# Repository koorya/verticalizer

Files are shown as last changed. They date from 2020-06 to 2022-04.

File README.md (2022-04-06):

# Вертикализатор

Репозиторий включает в себя несколько направлений разработки.
 - Hardware - проект схемы и разводки модернизированной печатной платы панели прибора
 - Production - материалы, передаваемые в производство платы
 - Firmware - состоит из двух частей: plc_cp1l - проект прошики ПЛК, python - submodule с примером общений с прибором из ПК
 - CAD - чертежи корпусов устройства
 - Docs - справочная информация по используемым компонентам

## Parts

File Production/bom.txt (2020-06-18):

Partlist exported from C:/Users/Puakt/Documents/EAGLE/projects/verticalizer/Hardware/panel.sch at 18.06.2020 19:30

Qty Value          Device         Package                           Parts                                                                                                                                              Description                                                                                                   MF    MPN OC_FARNELL OC_NEWARK POPULARITY SPICEPREFIX
1                  1,6/0,8        1,6/0,8                           PAD1                                                                                                                                               THROUGH-HOLE PAD                                                                                                                             15                    
1   0.1uF          CPOL-EUCT3216  CT3216                            C3                                                                                                                                                 POLARIZED CAPACITOR, European symbol                                                                                                         1          C          
1   0.33uF         CPOL-EUCT3216  CT3216                            C2                                                                                                                                                 POLARIZED CAPACITOR, European symbol                                                                                                         1          C          
1   10uF 16v       CPOL-EUCT3216  CT3216                            C1                                                                                                                                                 POLARIZED CAPACITOR, European symbol                                                                                                         1          C          
14  150            R-EU_R2512     R2512                             R48, R49, R50, R51, R52, R53, R54, R55, R56, R57, R58, R59, R60, R61                                                                               RESISTOR, European symbol                                                                                                                    0          R          
1   15k            R-EU_R0805     R0805                             R3                                                                                                                                                 RESISTOR, European symbol                                                                                                                    86         R          
7   2.2k           R-EU_R0805     R0805                             R14, R17, R20, R23, R26, R29, R32                                                                                                                  RESISTOR, European symbol                                                                                                                    86         R          
31  4.7k           R-EU_R0805     R0805                             R1, R4, R5, R6, R7, R8, R9, R10, R11, R12, R13, R15, R16, R18, R19, R21, R22, R24, R25, R27, R28, R30, R31, R33, R34, R36, R38, R40, R42, R44, R46 RESISTOR, European symbol                                                                                                                    86         R          
1   51             R-EU_R0805     R0805                             R2                                                                                                                                                 RESISTOR, European symbol                                                                                                                    86         R          
1   52746-20       52746-20       52746-20                          X2                                                                                                                                                 FPC Connector ZIF for SMT 0.5mm                                                                               MOLEX     9786350    unknown   0                     
5   7mm            TL11057MM      TL1105F                           S1, S2, S3, S4, S5                                                                                                                                                                                                                                                                                                    
7   800            R-EU_R0805     R0805                             R35, R37, R39, R41, R43, R45, R47                                                                                                                  RESISTOR, European symbol                                                                                                                    86         R          
1   B16B-PHDSS     B16B-PHDSS     B16B-PHDSS                        X1                                                                                                                                                 JST PHD series header 2.00mm pitch disconnectable crimp style connectors, vertical (side entry type), 16 pins                                                      
7   BC807-16LT1SMD BC807-16LT1SMD SOT23                             Q6, Q7, Q8, Q9, Q10, Q11, Q12                                                                                                                      PNP Transistror                                                                                                                              0                     
12  BC817-40LT1SMD BC817-40LT1SMD SOT23-BEC                         Q1, Q2, Q3, Q4, Q5, Q13, Q14, Q15, Q16, Q17, Q18, Q19                                                                                              NPN Transistor                                                                                                                               10                    
1   MC7805CDT      MC7805CDT      DPAK-3                            U1                                                                                                                                                 78xx SMD (D2PAK, DPAK)                                                                                                                                             
1   TSOP4838FLAT   TSOP4838FLAT   HDRVR14W64P250_1X14_2266X508X754B U$1                                                                                                                                                IR Receiver and Demodulator                                                                                                                                        
6   green          LEDGREEN_3MM   LED_GREEN_3MM                     LED2, LED3, LED4, LED5, LED6, LED7                                                                                                                 LED                                                                                                                                                                
1   red            LEDRED_3MM     LED_RED_3MM                       LED1                                                                                                                                               LED

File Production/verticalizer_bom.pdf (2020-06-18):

Комплект электронных компонентов для модификации вертикализатора.

кол-во | номинал | Device | Package | ссылка на магазин | изображение
1 | 0.1uF | CPOL-EUCT3216 | CT3216 | https://www.elitan.ru/price/item 444798 (https://www.elitan.ru/price/item444798)
1 | 0.33uF | CPOL-EUCT3216 | CT3216 | https://www.elitan.ru/price/item 531045 (https://www.elitan.ru/price/item531045)
1 | 10uF 16v | CPOL-EUCT3216 | CT3216 | https://www.elitan.ru/price/item 1692774 (https://www.elitan.ru/price/item1692774)
14 | 150ohm | R-EU_R2512 | R2512 | https://www.elitan.ru/price/item 13328558 (https://www.elitan.ru/price/item13328558)
1 | 15k | R-EU_R0805 | R0805
7 | 2.2k | R-EU_R0805 | R0805
31 | 4.7k | R-EU_R0805 | R0805

1 | 51ohm | R-EU_R0805 | R0805
7 | 800ohm | R-EU_R0805 | R0805
2 | 52746-20 | connector molex pn 527462033 | 52746-20 | https://www.elitan.ru/price/item 11015051 (https://www.elitan.ru/price/item11015051)
5 | 7mm | TL11057MM | TL1105F | https://www.elitan.ru/price/item 2132496 (https://www.elitan.ru/price/item2132496)
1 | B16B-PH DSS | B16B-PHDSS | B16B-PHDSS | https://www.elitan.ru/price/item 500178 (https://www.elitan.ru/price/item500178)
7 | BC807-16 LT1SMD | BC807-16LT1SMD | SOT23 | https://www.elitan.ru/price/item 77097 (https://www.elitan.ru/price/item77097)
12 | BC817-40 LT1SMD | BC817-40LT1SMD | SOT23-BEC | https://www.elitan.ru/price/item 1385191 (https://www.elitan.ru/price/item1385191)

1 | MC7805C DT | MC7805CDT | DPAK-3 | https://www.elitan.ru/price/item 99337 (https://www.elitan.ru/price/item99337)
1 | TSOP483 8FLAT | TSOP4838FLAT | HDRVR14W64P250_1X14_ 2266X508X754B | https://www.elitan.ru/price/item 127075 (https://www.elitan.ru/price/item127075)
6 | green | LEDGREEN_3MM | LED_GREEN_3MM | https://www.elitan.ru/price/item 16824792 (https://www.elitan.ru/price/item16824792)
1 | red | LEDRED_3MM | LED_RED_3MM | https://www.elitan.ru/price/item 16824793 (https://www.elitan.ru/price/item16824793)
1 | 2РМТ24КПН19Ш1В 1В | вилка на кабель | https://www.elitan.ru/price/item 260370335 (https://www.elitan.ru/price/item260370335)
1 | 2РМТ24БПЭ19Г1В 1В | розетка на блок | https://www.elitan.ru/price/item 211260919 (https://www.elitan.ru/price/item211260919)

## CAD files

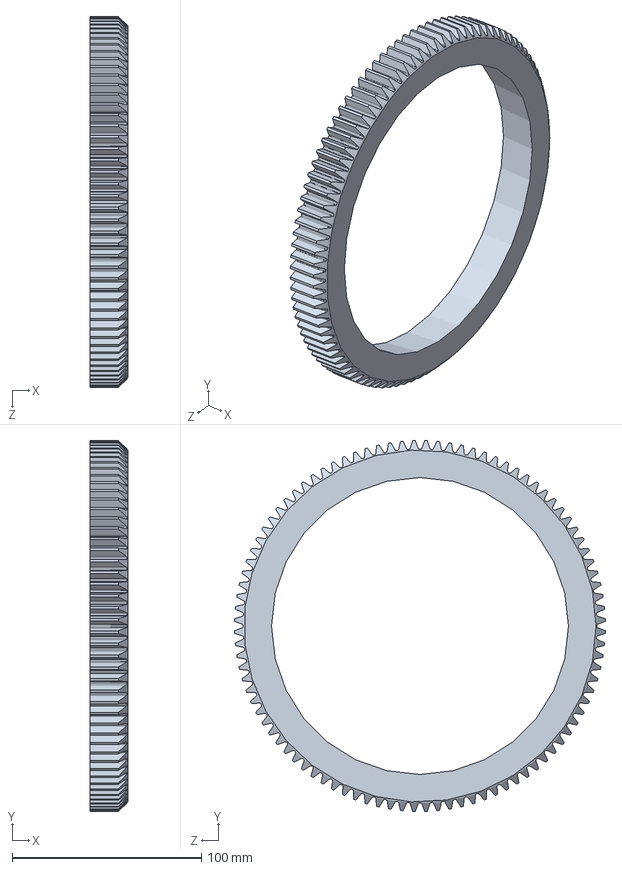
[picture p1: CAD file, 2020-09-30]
CAD/gears/DIN - Spur gear 2M 96T 20PA 12FW ---S96A75H50L155N новожилов.SLDPRT
20.0 x 195.9 x 195.9 mm

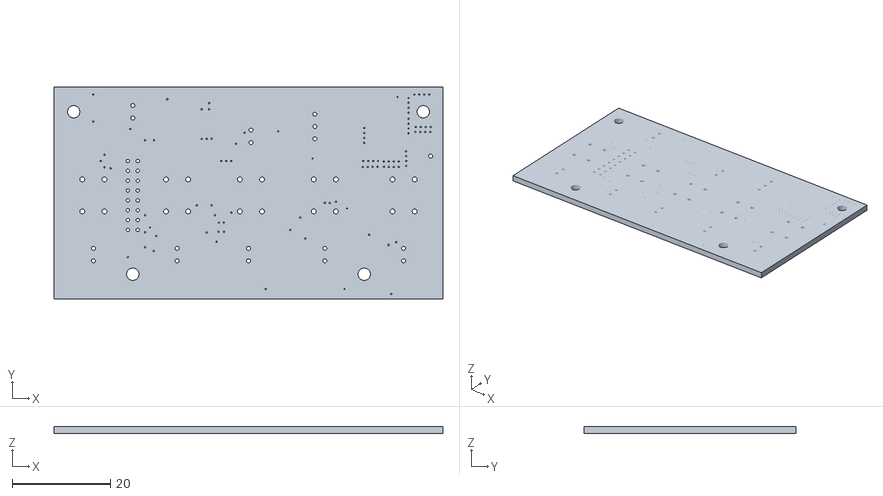
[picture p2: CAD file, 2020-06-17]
Production/Board.stl
79.0 x 43.0 x 1.50

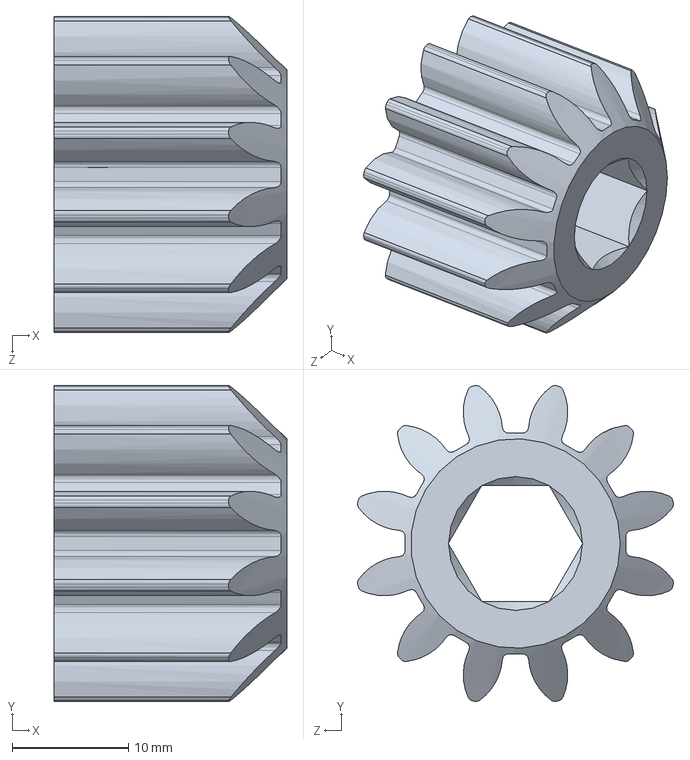
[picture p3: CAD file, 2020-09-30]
CAD/gears/DIN - Spur gear 2M 12T 20PA 16FW ---S12A75H50L6N новожилов.SLDPRT
20.0 x 27.1 x 27.1 mm

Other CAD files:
CAD/gears/DIN - Spur gear 2M 12T 20PA 16FW ---S12A75H50L6N новожилов.STL
CAD/gears/DIN - Spur gear 2M 96T 20PA 12FW ---S96A75H50L155N новожилов.STL
CAD/РФГМ-80 0210 Корпус шлейфа.x_t

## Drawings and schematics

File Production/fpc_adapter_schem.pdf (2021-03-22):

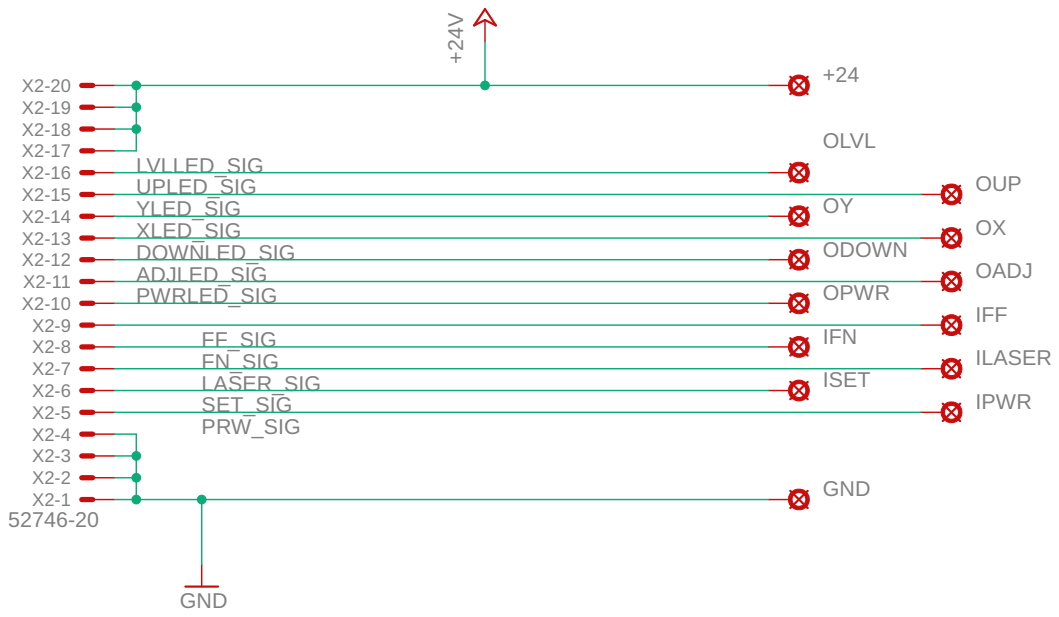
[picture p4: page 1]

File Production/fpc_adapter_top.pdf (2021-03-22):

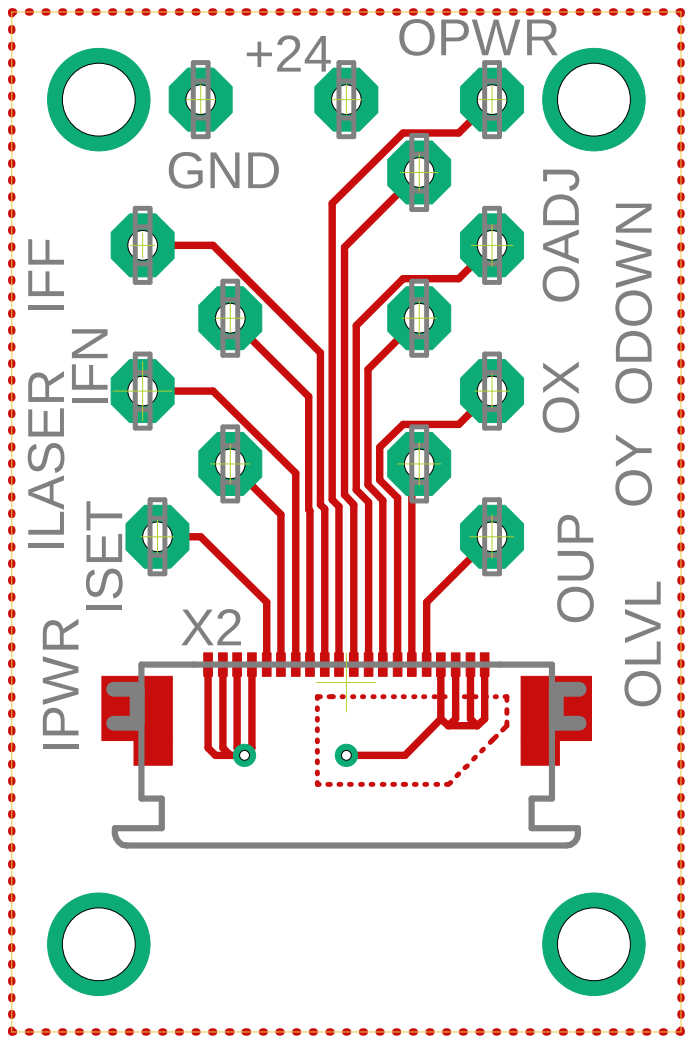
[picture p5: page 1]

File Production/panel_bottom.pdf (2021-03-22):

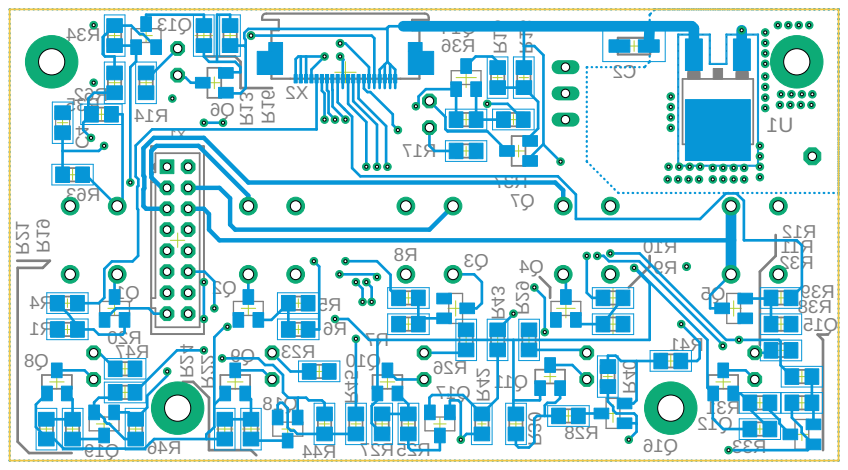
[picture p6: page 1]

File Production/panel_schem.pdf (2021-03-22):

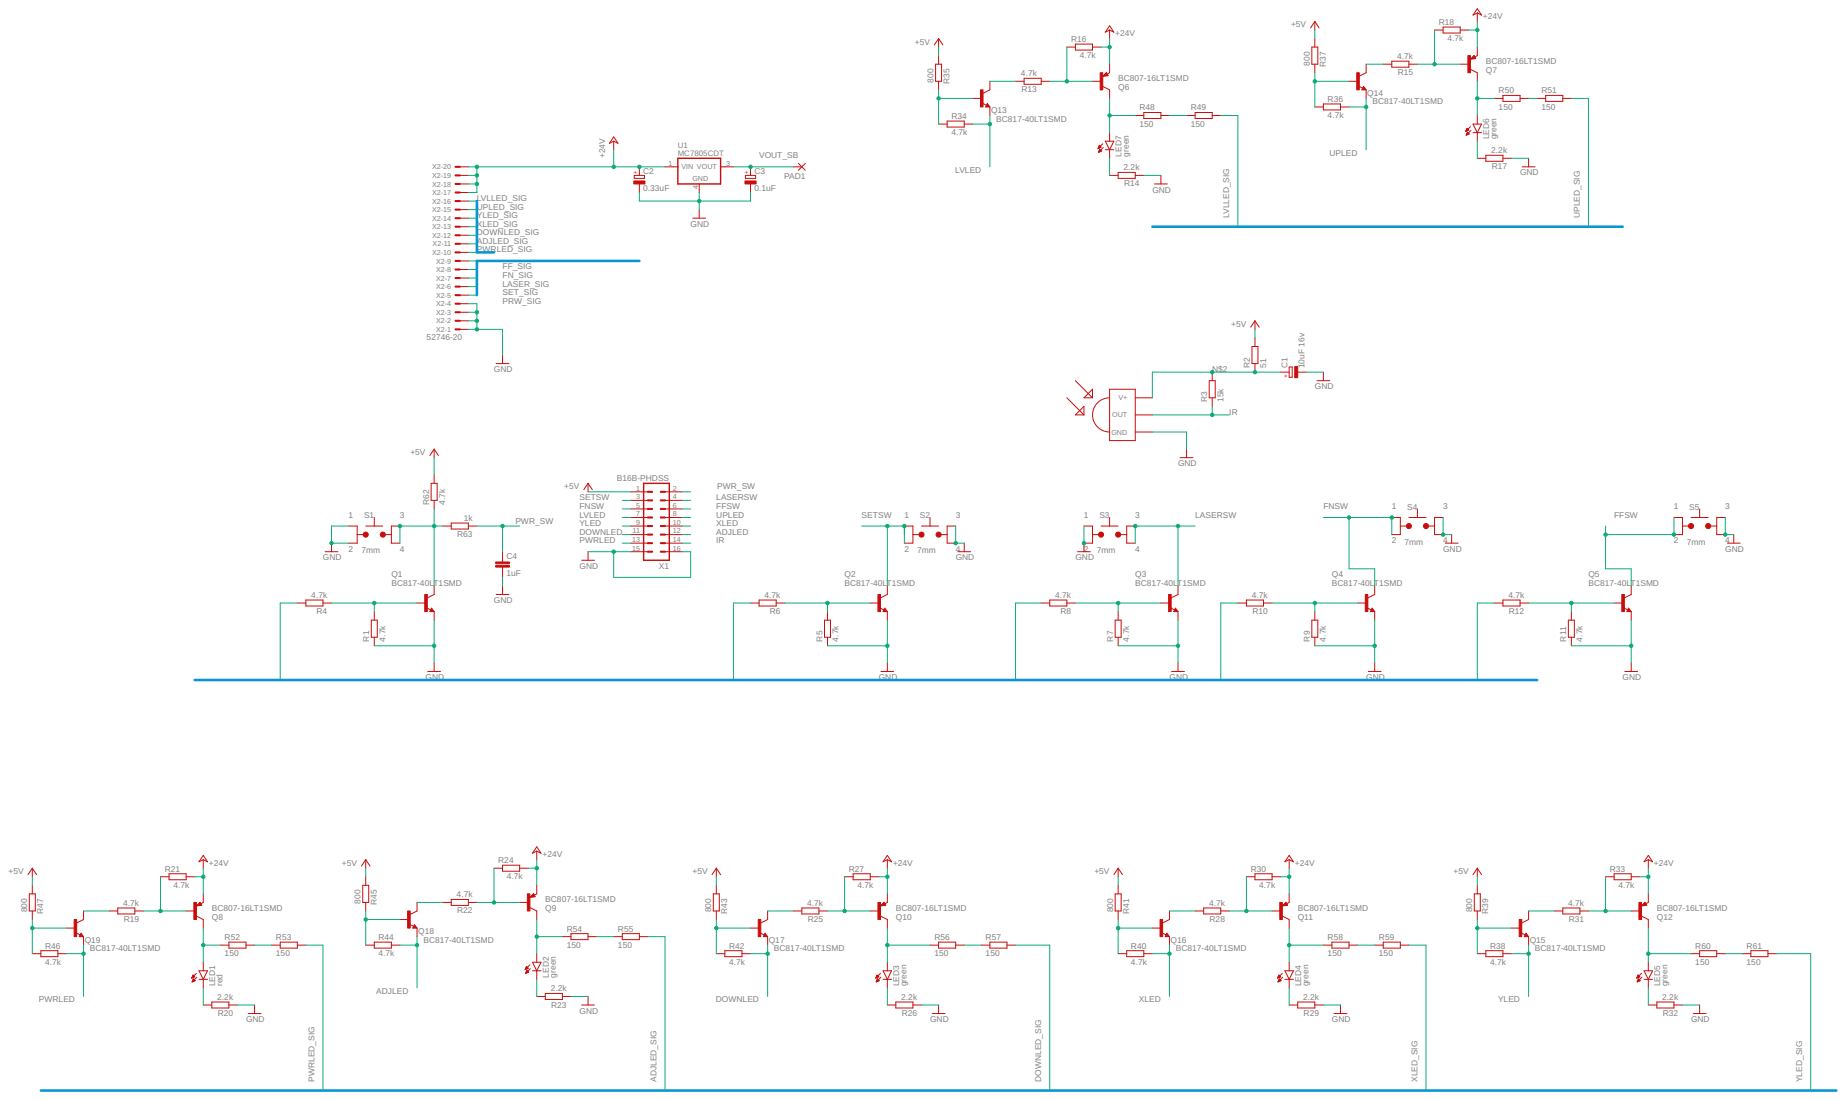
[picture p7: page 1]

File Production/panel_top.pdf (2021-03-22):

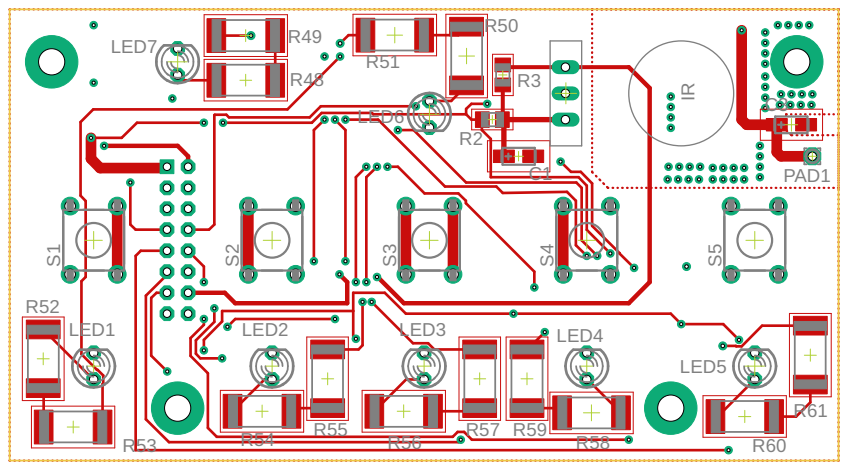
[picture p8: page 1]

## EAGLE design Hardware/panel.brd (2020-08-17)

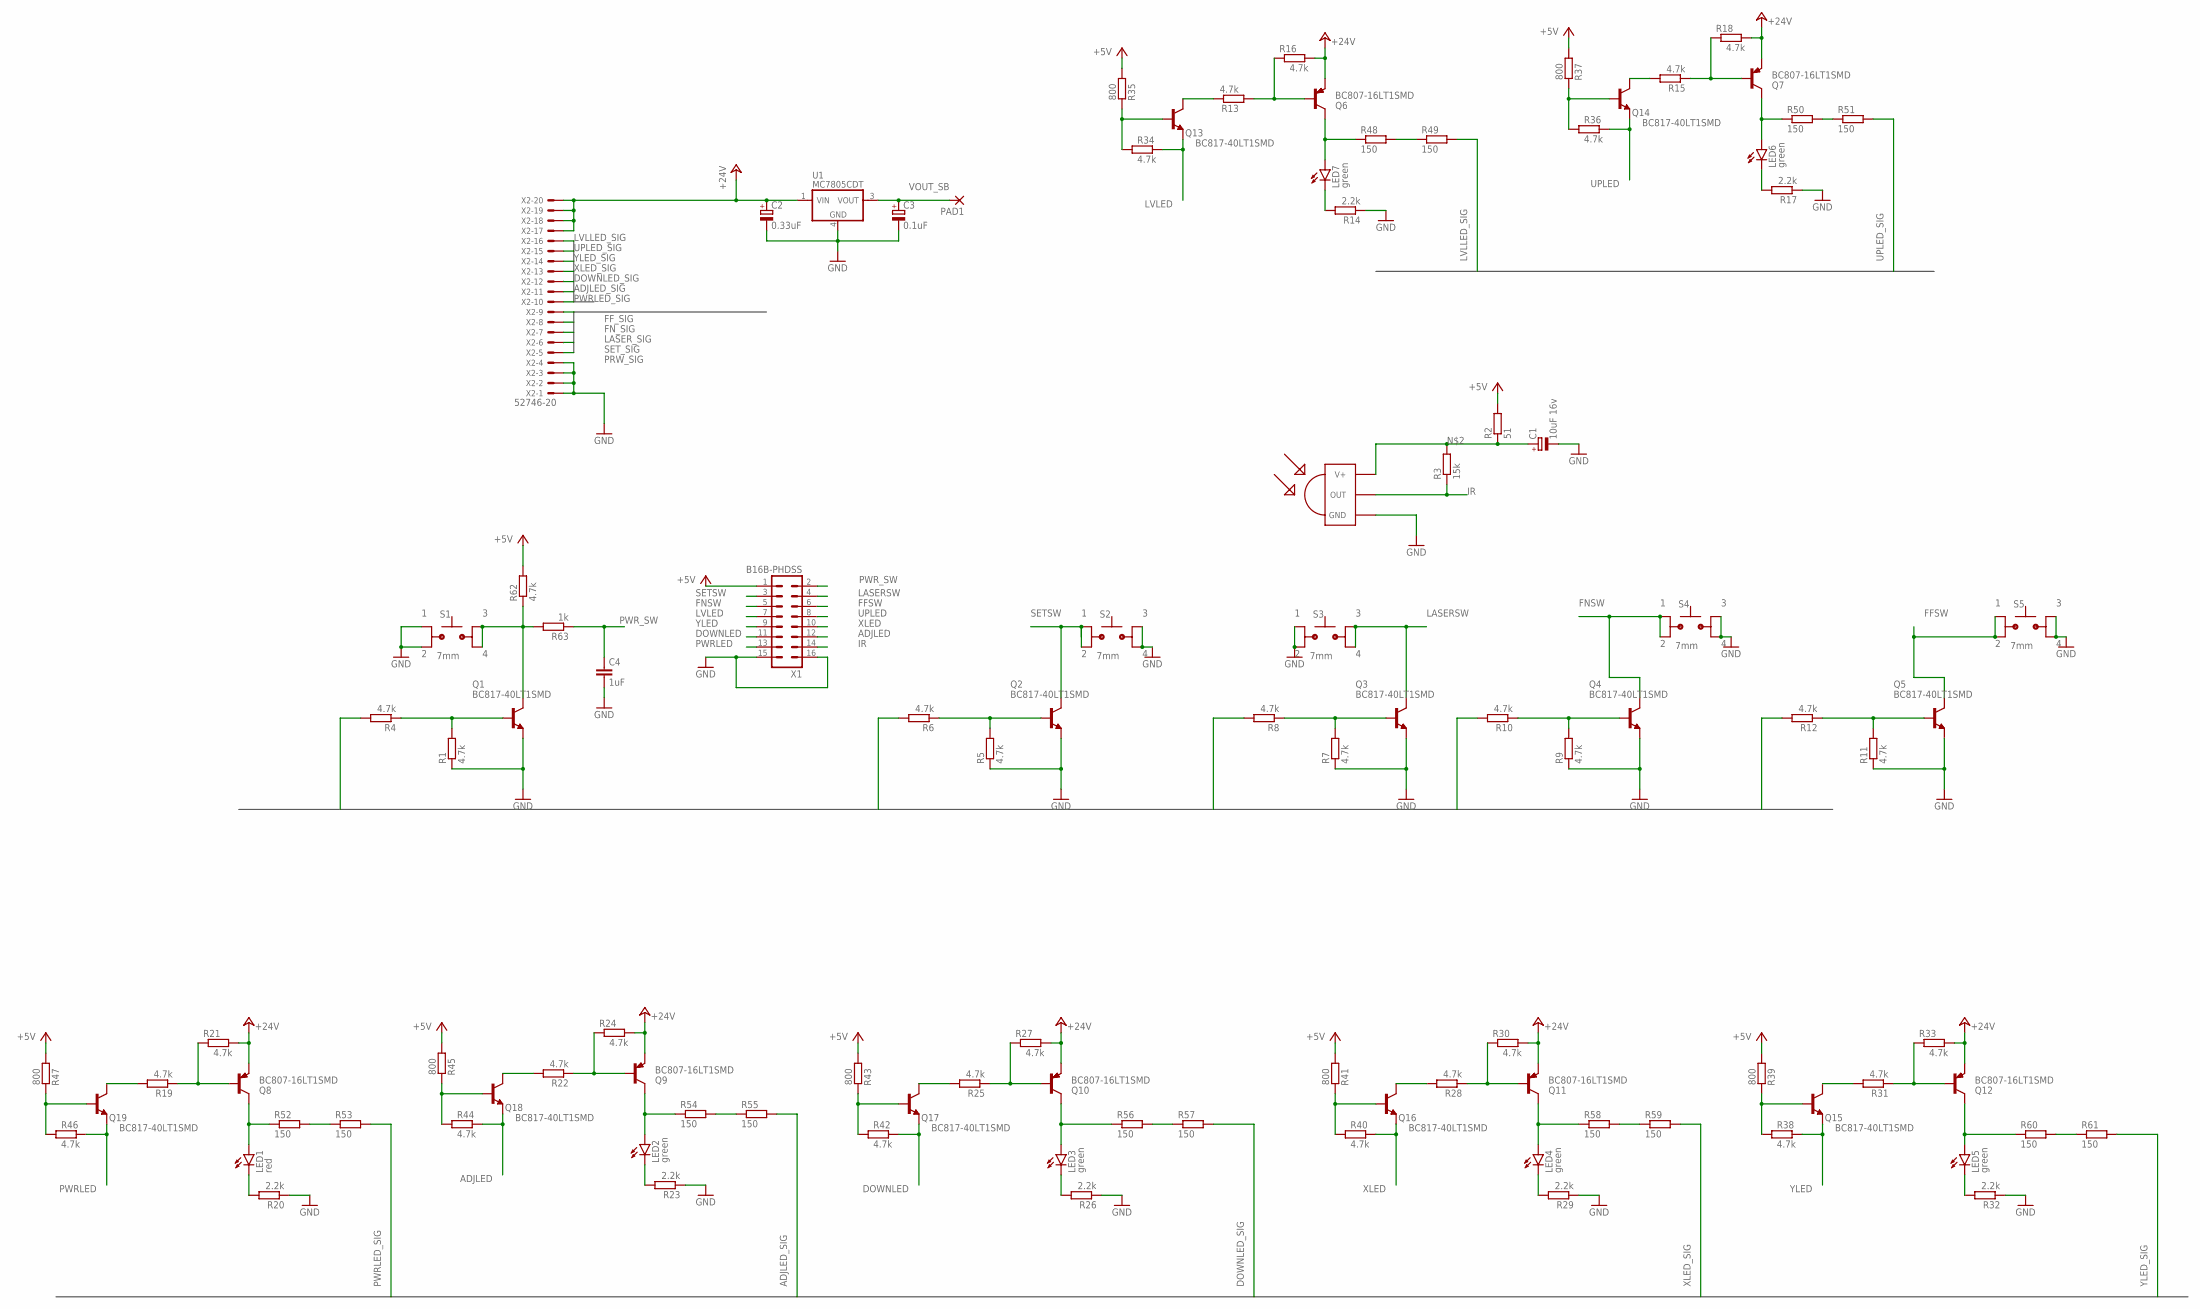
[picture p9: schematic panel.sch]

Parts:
C1: 10uF 16v; CT3216
C2: 0.33uF; CT3216
C3: 0.1uF; CT3216
C4: 1uF; C0805
LED1: red; LED_RED_3MM
LED2, LED3, LED4, LED5, LED6, LED7: green; LED_GREEN_3MM
PAD1: 1,6/0,8
Q1, Q2, Q3, Q4, Q5, Q13, Q14, Q15, Q16, Q17, Q18, Q19: BC817-40LT1SMD; SOT23-BEC
Q6, Q7, Q8, Q9, Q10, Q11, Q12: BC807-16LT1SMD; SOT23
R1, R4, R5, R6, R7, R8, R9, R10, R11, R12, R13, R15, R16, R18, R19, R21, R22, R24, R25, R27, R28, R30, R31, R33, R34, R36, R38, R40, R42, R44, R46, R62: 4.7k; R0805
R2: 51; R0805
R3: 15k; R0805
R14, R17, R20, R23, R26, R29, R32: 2.2k; R0805
R35, R37, R39, R41, R43, R45, R47: 800; R0805
R48, R49, R50, R51, R52, R53, R54, R55, R56, R57, R58, R59, R60, R61: 150; R2512
R63: 1k; R0805
S1, S2, S3, S4, S5: 7mm; TL1105F
U1: MC7805CDT; DPAK-3
U$1: TSOP4838FLAT; HDRVR14W64P250_1X14_2266X508X754B
X1: B16B-PHDSS
X2: 52746-20

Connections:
+5V: R2.2, R35.1, R37.1, R39.1, R41.1, R43.1, R45.1, R47.1, R62.2, X1.1
+24V: C2.+, Q6.2 (E), Q7.2 (E), Q8.2 (E), Q9.2 (E), Q10.2 (E), Q11.2 (E), Q12.2 (E), R16.2, R18.2, R21.2, R24.2, R27.2, R30.2, R33.2, U1.1 (VIN), X2.17, X2.18, X2.19, X2.20
ADJLED: Q18.E, R44.2, X1.12
ADJLED_SIG: R55.2, X2.11
DOWNLED: Q17.E, R42.2, X1.11
DOWNLED_SIG: R57.2, X2.12
FFSW: Q5.C, S5.1 (0), S5.3 (0), X1.6
FF_SIG: R12.2, X2.9
FNSW: Q4.C, S4.1 (0), S4.3 (0), X1.5
FN_SIG: R10.2, X2.8
GND: C1.-, C2.-, C3.-, C4.2, Q1.E, Q2.E, Q3.E, Q4.E, Q5.E, R1.1, R5.1, R7.1, R9.1, R11.1, R14.1, R17.1, R20.1, R23.1, R26.1, R29.1, R32.1, S1.1 (0), S1.3 (0), S2.2 (1), S2.4 (1), S3.1 (0), S3.3 (0), S4.2 (1), S4.4 (1), S5.2 (1), S5.4 (1), U1.4 (GND), U$1.GND, X1.15, X1.16, X2.1, X2.2, X2.3, X2.4
IR: R3.1, U$1.OUT, X1.14
LASERSW: Q3.C, S3.2 (1), S3.4 (1), X1.4
LASER_SIG: R8.2, X2.7
LVLED: Q13.E, R34.2, X1.7
LVLLED_SIG: R49.2, X2.16
unnamed: Q1.B, R1.2, R4.1
unnamed: C1.+, R2.1, R3.2, U$1.VCC (V+)
unnamed: LED7.A, Q6.3 (C), R48.1
unnamed: Q2.B, R5.2, R6.1
unnamed: Q3.B, R7.2, R8.1
unnamed: Q4.B, R9.2, R10.1
unnamed: Q5.B, R11.2, R12.1
unnamed: Q6.1 (B), R13.1, R16.1
unnamed: Q13.C, R13.2
unnamed: LED7.K (C), R14.2
unnamed: Q14.B, R36.1, R37.2
unnamed: Q7.1 (B), R15.1, R18.1
unnamed: LED6.K (C), R17.2
unnamed: Q8.1 (B), R19.1, R21.1
unnamed: LED1.K (C), R20.2
unnamed: Q9.1 (B), R22.1, R24.1
unnamed: LED2.K (C), R23.2
unnamed: Q10.1 (B), R25.1, R27.1
unnamed: LED3.K (C), R26.2
unnamed: Q11.1 (B), R28.1, R30.1
unnamed: LED4.K (C), R29.2
unnamed: Q12.1 (B), R31.1, R33.1
unnamed: LED5.K (C), R32.2
unnamed: Q13.B, R34.1, R35.2
unnamed: Q14.C, R15.2
unnamed: Q15.B, R38.1, R39.2
unnamed: Q15.C, R31.2
unnamed: Q16.B, R40.1, R41.2
unnamed: Q16.C, R28.2
unnamed: Q17.B, R42.1, R43.2
unnamed: Q17.C, R25.2
unnamed: Q18.B, R44.1, R45.2
unnamed: Q18.C, R22.2
unnamed: Q19.B, R46.1, R47.2
unnamed: Q19.C, R19.2
unnamed: R48.2, R49.1
unnamed: LED6.A, Q7.3 (C), R50.1
unnamed: R50.2, R51.1
unnamed: LED1.A, Q8.3 (C), R52.1
unnamed: R52.2, R53.1
unnamed: LED2.A, Q9.3 (C), R54.1
unnamed: R54.2, R55.1
unnamed: LED3.A, Q10.3 (C), R56.1
unnamed: R56.2, R57.1
unnamed: LED4.A, Q11.3 (C), R58.1
unnamed: R58.2, R59.1
unnamed: LED5.A, Q12.3 (C), R60.1
unnamed: R60.2, R61.1
unnamed: Q1.C, R62.1, R63.2, S1.2 (1), S1.4 (1)
PRW_SIG: R4.2, X2.5
PWRLED: Q19.E, R46.2, X1.13
PWRLED_SIG: R53.2, X2.10
PWR_SW: C4.1, R63.1, X1.2
SETSW: Q2.C, S2.1 (0), S2.3 (0), X1.3
SET_SIG: R6.2, X2.6
UPLED: Q14.E, R36.2, X1.8
UPLED_SIG: R51.2, X2.15
VOUT_SB: C3.+, PAD1.1, U1.3 (VOUT)
XLED: Q16.E, R40.2, X1.10
XLED_SIG: R59.2, X2.13
YLED: Q15.E, R38.2, X1.9
YLED_SIG: R61.2, X2.14

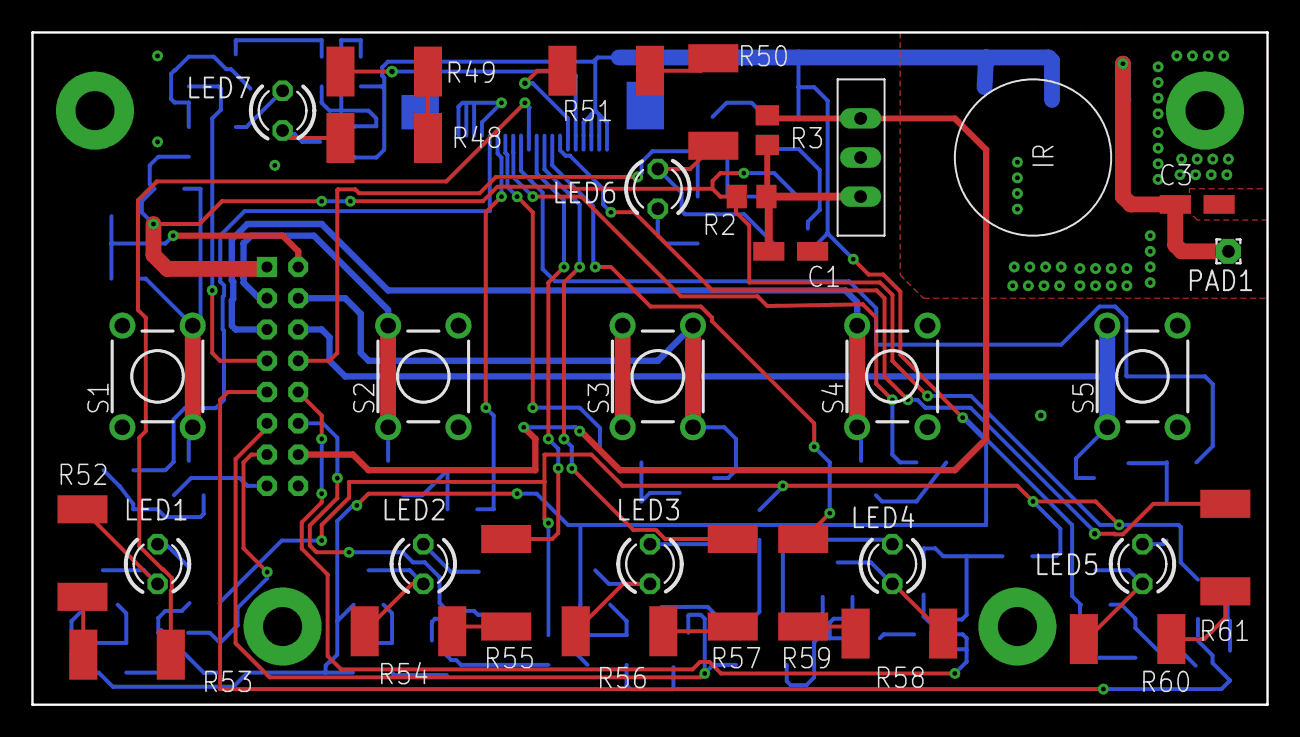
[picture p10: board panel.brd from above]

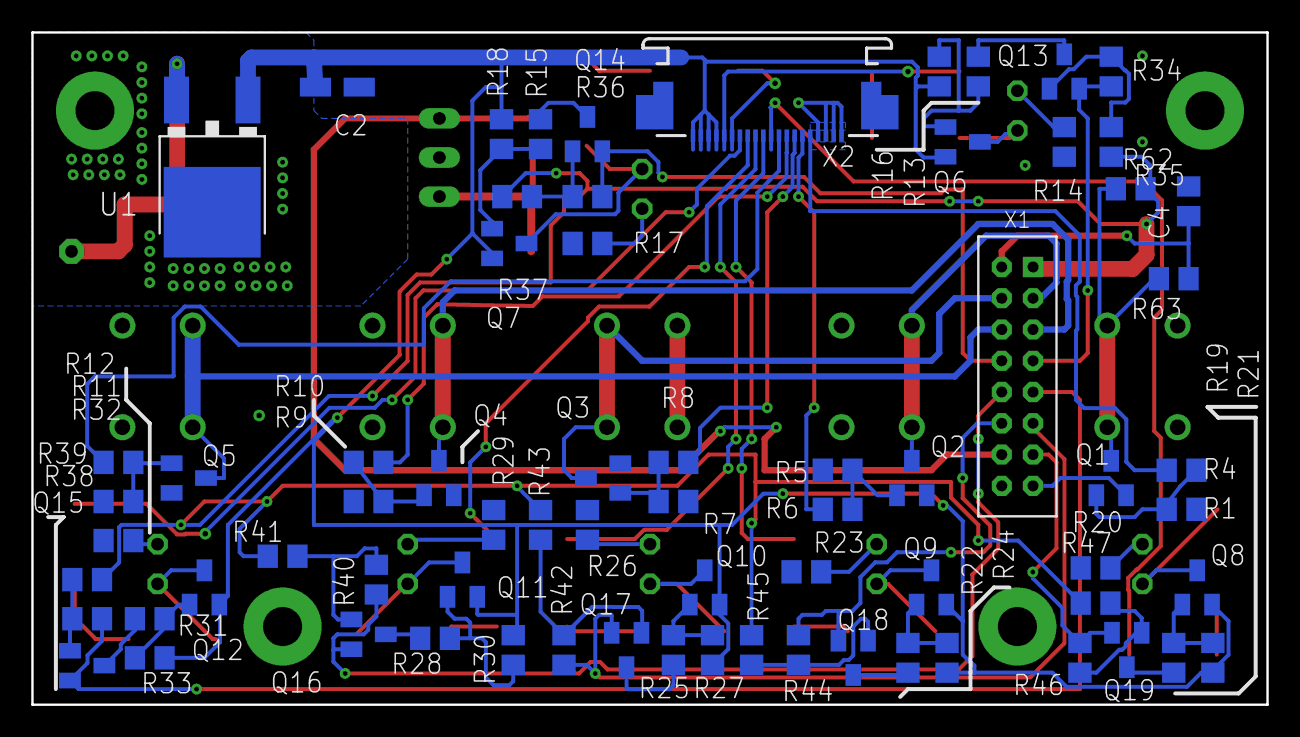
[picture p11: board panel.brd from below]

Board: 2 copper layers, 79.0 x 43.0 mm, 103 parts (71 on the bottom side), 78 nets.

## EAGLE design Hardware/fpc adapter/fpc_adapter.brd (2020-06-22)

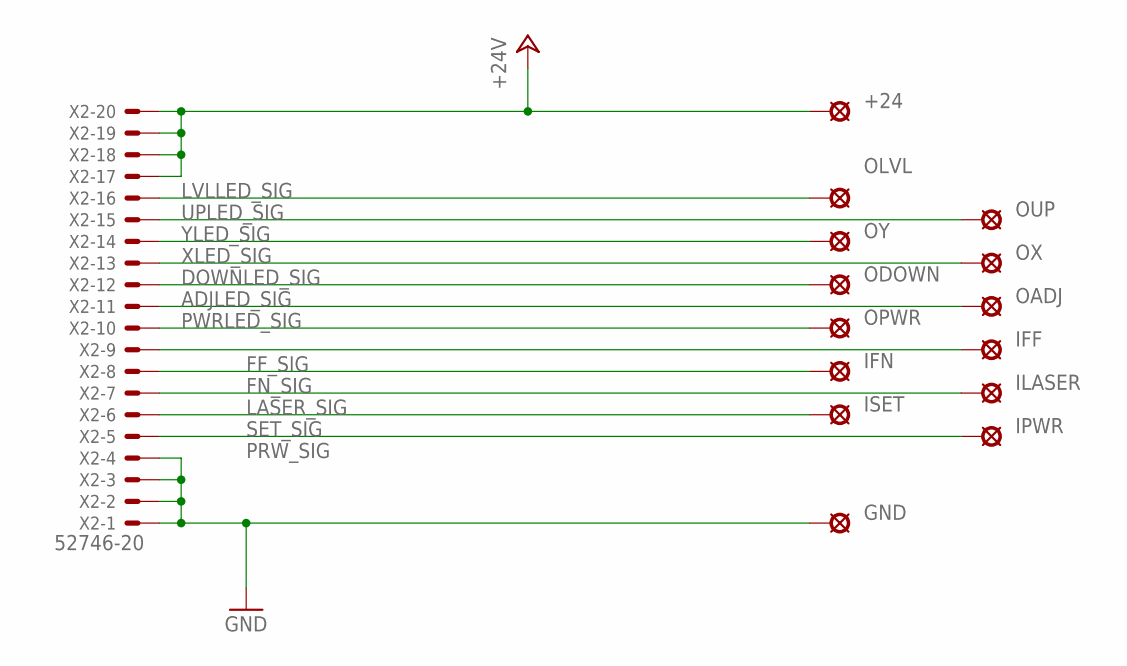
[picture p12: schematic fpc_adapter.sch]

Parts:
+24: LSP10
GND: LSP10
IFF: LSP10
IFN: LSP10
ILASER: LSP10
IPWR: LSP10
ISET: LSP10
OADJ: LSP10
ODOWN: LSP10
OLVL: LSP10
OPWR: LSP10
OUP: LSP10
OX: LSP10
OY: LSP10
X2: 52746-20

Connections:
+24V: +24.MP, X2.17, X2.18, X2.19, X2.20
ADJLED_SIG: OADJ.MP, X2.11
DOWNLED_SIG: ODOWN.MP, X2.12
FF_SIG: IFF.MP, X2.9
FN_SIG: IFN.MP, X2.8
GND: GND.MP, X2.1, X2.2, X2.3, X2.4
LASER_SIG: ILASER.MP, X2.7
LVLLED_SIG: OLVL.MP, X2.16
PRW_SIG: IPWR.MP, X2.5
PWRLED_SIG: OPWR.MP, X2.10
SET_SIG: ISET.MP, X2.6
UPLED_SIG: OUP.MP, X2.15
XLED_SIG: OX.MP, X2.13
YLED_SIG: OY.MP, X2.14

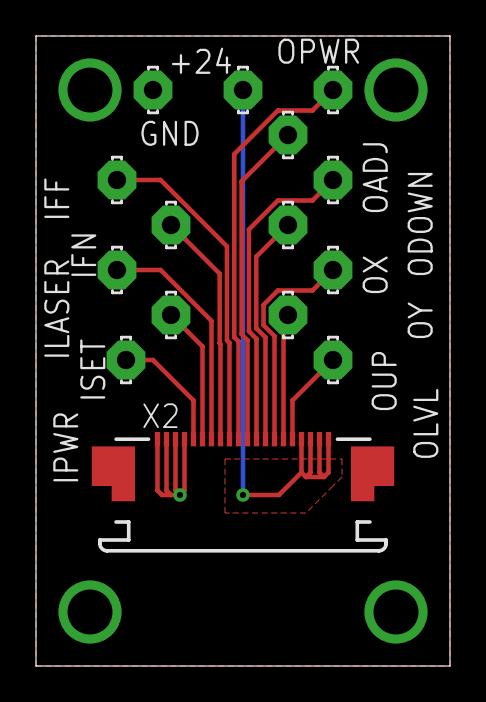
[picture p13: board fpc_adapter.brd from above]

Board: 2 copper layers, 23.0 x 35.0 mm, 15 parts (0 on the bottom side), 14 nets.

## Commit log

2020-06-15 init commit
    [panel.brd, panel.sch]
2020-06-15 test commit
    [panel.sch]
2020-06-16 разъем под шлейф,вывод для штатного питания прибора. Сделал цепи комутации кнопок на транзисторе.
    [panel.brd, panel.sch]
2020-06-16 переподключил индикаторы через транзисторы. это надо испытать
    [panel.brd, panel.sch]
2020-06-16 сделал разводку управляющих и индикаторных цепей на транзисторах. еще не проверял работоспособность решений.
    [panel.brd, panel.sch]
2020-06-16 заменил библиотеку transistor-pnp на пользовательскую, скопировав исходную. Таким образом ушел глюк с исчезновением корпусов транзисторов bc807
    [panel.brd, panel.sch]
2020-06-16 нажал кнопку обновить библиотеки,чтобы компоненты на плате обновились
    [panel.brd, panel.sch]
2020-06-17 изменил диаметры переходных отверстий с 0.35 на 0.3 мм
    [panel.brd]
2020-06-17 по результатам эксперимента с кнопками и индикаторами все нормально. оявилась идея добавить защитные резисторы на индикаторные выходы,чтобы не сгорал транзистор в случае кз на землю
    [panel.brd, panel.sch]
2020-06-17 добавил файл печатной платы в stl чтобы проверить по отверстиям
    [Board.stl]
2020-06-18 Создал схему и плату переходника с провода на шлейф
    [fpc_adapter.brd, fpc_adapter.sch]
2020-06-18 сделал плату более узкой,чтоб она помещалась в дырку под разъем
    [fpc_adapter.brd]
2020-06-18 подготовил файлы для заказа в электроконнекте,а так же сделал пдф со списком компонентов
    [Blank_PS-Electro_verticalizer_fpc_adapter_PCB_Gerber.xls, Blank_PS-Electro_verticalizer_panel_PCB_Gerber.xls, fpc_adapter.brd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]
2020-06-22 по требованию с производства увеличил зазорполигона до 0,2мм на обеих платах. заказ переделал. заказе указал покрытие ПОС 63 вместо имерсионного олова
    [Blank_PS-Electro_verticalizer_fpc_adapter_PCB_Gerber.xls, Blank_PS-Electro_verticalizer_panel_PCB_Gerber.xls, fpc_adapter.brd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]
2020-06-22 заархивировал файлы заказа, именно этот архив сегодня я отправил по почте
2020-08-17 добавлен файл проект плк
    [РФГМ-80 0210 Корпус шлейфа.x_t]
2020-08-17 добавил RC-цепочку для устранения дребезга
    [panel.brd, panel.sch]
2020-08-17 экспеиментально подобрал параметры цепочки кнопки питания, чтобы она срабатывала без проблем
    [panel.brd, panel.sch]
2020-08-19 изменил программу плк,чтобы была возможность управлять им из скрипта на компьютере
2020-08-19 в качестве подмодуля добавил скрипт на питоне, позволяющий управлять прибором с компьютера
2020-09-30 добавлено две модели шестерен от новожилова
    [DIN - Spur gear 2M 12T 20PA 16FW ---S12A75H50L6N новожилов.SLDPRT, DIN - Spur gear 2M 12T 20PA 16FW ---S12A75H50L6N новожилов.STL, DIN - Spur gear 2M 96T 20PA 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]
2020-09-30 указал, где искать файлы моделей
2020-09-30 удалил подмодуль
2020-09-30 добавил подмодуль
2021-03-22 добавил pdf со схемами и слоями
2021-03-23 добавил комментарии в программу для
2021-03-23 добавил gitignore в подмодуль
2021-03-23 добавил комментарии к программе на питоне
